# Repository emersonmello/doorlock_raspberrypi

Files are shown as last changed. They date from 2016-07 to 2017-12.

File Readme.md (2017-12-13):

# Door lock NFC card reader for Raspberry PI

## Motivation

Is it possible to use [FIDO UAF Standard](https://fidoalliance.org/specifications/download/) on an Android mobile + NFC to opening doors?

This project is a simple prototype to verify how FIDO could be used in this scenario (see [FIDO Security Reference](https://fidoalliance.org/specs/fido-uaf-v1.0-ps-20141208/fido-security-ref-v1.0-ps-20141208.html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)). This [card reader](https://github.com/emersonmello/doorlock_raspberrypi) uses NFC to communicate with a specific [Android Opening Door App](https://github.com/emersonmello/openingdoor), that emulates a NFC card using Android's [Host-based Card Emulation](https://developer.android.com/guide/topics/connectivity/nfc/hce.html) functionality.

The [card reader](https://github.com/emersonmello/doorlock_raspberrypi) and [Android Opening Door App](https://github.com/emersonmello/openingdoor) depend of a third-party, called [FIDO UAF RP Server](https://github.com/emersonmello/UAF).

Figure below shows all necessary components and the relation between them

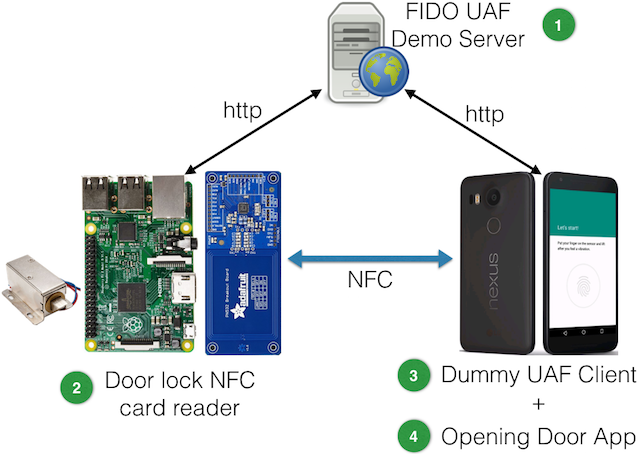
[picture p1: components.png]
Communication diagram


1. [FIDO UAF Demo Server](https://github.com/emersonmello/UAF)
  - If you prefer, there is a [Docker container](https://www.docker.com/what-docker) ready to use here: https://github.com/emersonmello/docker-fidouafserver
2. [Door lock NFC card reader](https://github.com/emersonmello/doorlock_raspberrypi) <- You are working on it right now!
3. [Dummy FIDO UAF Client](https://github.com/emersonmello/dummyuafclient)
4. [Opening Door Android App](https://github.com/emersonmello/openingdoor)

## Hardware requirements

- 01 [Raspberry PI 2 B](https://www.raspberrypi.org/products/raspberry-pi-2-model-b/) or 01 [Raspberry PI 3 B](https://www.raspberrypi.org/products/raspberry-pi-3-model-b/)
- 01 [Adafruit PN532](https://www.adafruit.com/products/364) or 01 [Elechouse PN532 NFC RFID module V3](http://www.elechouse.com/elechouse/index.php?main_page=product_info&cPath=90_93&products_id=2242)
- 01 Breadboard to connect raspberry and PN532
- 01 [N channel MOSFET](https://www.adafruit.com/products/355)
- 01 [Lock-style solenoid](https://www.adafruit.com/product/1512)
- 02 Resistors - 300 Ohms
- 02 LED (red and green)
- 02 [Diode 1N4001](https://www.adafruit.com/product/755)

### Wiring Raspberry PI 2 B (or Raspberry PI 3 B) & PN532

1. To use UART on [Adafruit PN532](https://www.adafruit.com/products/364) breakout you must set to **OFF** the **SEL0** and **SEL1** jumpers
   1. To use UART on [Elechouse PN532 NFC RFID module V3](http://www.elechouse.com/elechouse/index.php?main_page=product_info&cPath=90_93&products_id=2242) you must set to **OFF** the **switch 1** and **switch 2**.
2. Follow instructions (and pictures) below to connect all components

| Raspberry PI (2 or 3) B | Wire color | Adafruit PN532 | Elechouse PN532 |
| --- | :---: | :---: | :---: |
| Pin 2 (5v) | RED | 5.0V | VCC |
| Pin 6 (ground) | BLACK | GND | GND |
| Pin 8 (BCM 14 TXD) | YELLOW | RXD | SCL (RX) |
| Pin 10 (BCM 15 RXD) | GREEN | TXD | SDA (TX) |

| Raspberry PI 2 or 3 B | Wire color | Component on breadboard  |
| --- | :---: | :---: |
| Pin 11 (BCM 17) | ORANGE | Green LED anode (+) |
| Pin 13 (BCM 27) | BLUE | RED LED anode (+) |
| Pin 15 (BCM 22) | PURPLE | Diode #1 anode (+) |
| Pin 39 (Ground) | BLACK | Breadboard negative rail |

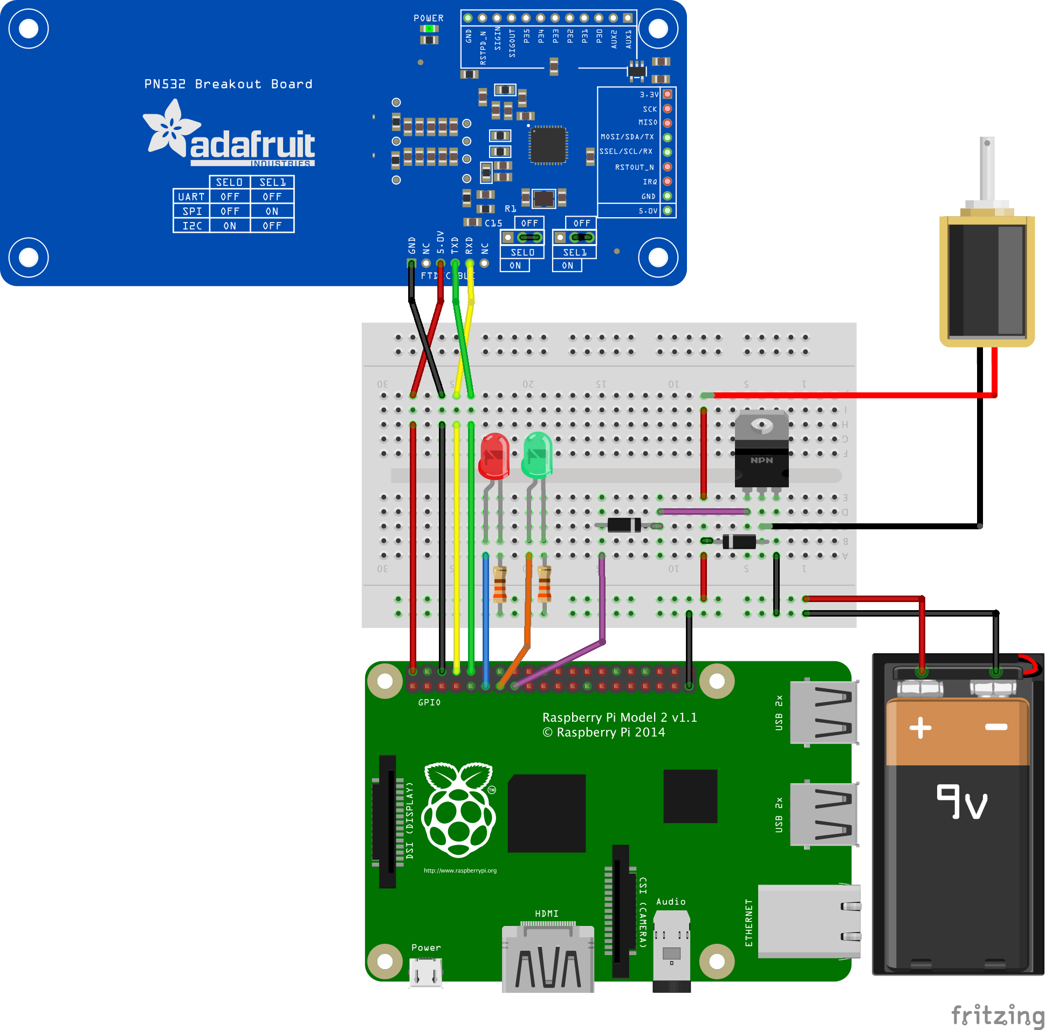
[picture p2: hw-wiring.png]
Using Adafruit PN532 Wiring raspberry PI 2/3 B & Adafruit PNB532 & solenoid


Or, if you have an Elechouse PN532:

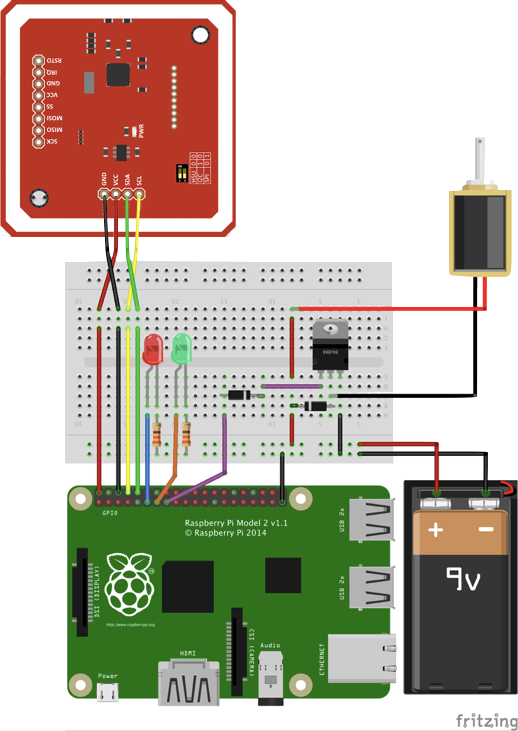
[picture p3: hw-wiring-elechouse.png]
Using Elechousr PN532 Wiring raspberry PI 2/3 B & Elechouse PNB532 & solenoid


## Software requirements

- [Libcurl](https://curl.haxx.se/libcurl/)
- [Libnfc >= 1.7.1](https://github.com/nfc-tools/libnfc)
- [Json-c >= 0.11-4](https://github.com/json-c/json-c)
- [wiringPi library](http://wiringpi.com/)

### Installing required packages

	sudo apt-get install git build-essential autoconf libtool libpcsclite-dev
	sudo apt-get install libusb-dev libcurl4-openssl-dev libjson-c-dev

### Freeing [UART](https://www.raspberrypi.org/documentation/configuration/uart.md)

  sudo raspi-config

#### On the Raspberry PI 2 B running Raspbian GNU/Linux 8

- Select option  "Advanced Options"
- Select option "Serial" and select **NO**
- Finish and reboot: `sudo shutdown -r now`

#### On the Raspberry PI 3 B running Raspbian Stretch

- Select option "Interface options"
- Select option "Serial", and select **NO**
  - Choose **YES** for *Would you like the serial port hardware to be enable?*  
- Exit and reboot

### Installing libnfc from source

```cd ~ && sudo mkdir -p /etc/nfc/devices.d
git clone https://github.com/nfc-tools/libnfc.git
cd libnfc
sudo mkdir -p /etc/nfc/devices.d/
```

#### On the Raspberry PI 2 B

`sudo cp contrib/libnfc/pn532_uart_on_rpi.conf.sample /etc/nfc/devices.d/pn532_uart_on_rpi.conf`

`echo "allow_instrusive_scan =  true" | sudo tee -a  /etc/nfc/devices.d/pn532_uart_on_rpi.conf`

#### On the Raspberry PI 3 B

`sudo cp contrib/libnfc/pn532_uart_on_rpi_3.conf.sample /etc/nfc/devices.d/pn532_uart_on_rpi_3.conf`

#### Run config & build

	autoreconf -vis
	./configure --with-drivers=pn532_uart --sysconfdir=/etc --prefix=/usr
	sudo make clean && sudo make install all

#### Testing

You can test your setup reading an ISO14443-A card using `nfc-poll` program that came with `libnfc`. Place a card on the reader and run the command:

	cd ~/libnfc/examples
	sudo ./nfc-poll

### Installing wiringPi from source

- Please, follow the instructions provided by [official website](http://wiringpi.com/download-and-install). Or

- ```
  git clone git://git.drogon.net/wiringPi
  cd ~/wiringPi
  sudo ./build
  ```

## Running door lock NFC card reader on Raspberry PI

1. Get the source code
- `cd ~ && git clone https://github.com/emersonmello/doorlock_raspberrypi.git`
- `cd doorlock_raspberrypi`
2. Change **HOSTNAME** and **PORT** values on [Door lock NFC card reader's rp_settings.h file](https://github.com/emersonmello/doorlock_raspberrypi/blob/master/rp_settings.h) to the **IP Address** and **PORT** where you are running the **FIDO UAF Demo Server**
  - For instance: `nano rp_settings.h`
3. Compile **Door lock NFC card reader** project
  - `make clean && make`
4. Run it (sorry, you must be root because it is a requirement of wiringPi lib)
    - For instance: `sudo ./dist/Debug/GNU-MacOSX/doorlock_raspberrypi`

### Setting up FIDO UAF Demo Server and Android Apps

#### FIDO UAF Demo Server

1. Start **FIDO UAF Demo Server**
- Follow the instructions provided by:
  - [FIDO UAF Demo Server](https://github.com/emersonmello/UAF)
  - Or, if you prefer, there is a [Docker container](https://www.docker.com/what-docker) ready to use [here](https://github.com/emersonmello/docker-fidouafserver)

#### On Android Phone

1. Install [Dummy FIDO UAF Client](https://github.com/emersonmello/dummyuafclient) on your Android phone
2. Install [Opening Door Android App](https://github.com/emersonmello/openingdoor) on your Android phone
3. On **Opening Door Android App** touch on "Settings" on the main application menu and update "server endpoint" field to the **IP Address** and **PORT** where you are running the **FIDO UAF Demo Server**  
4. On **Opening Door Android App** touch on "Whitelisting facetID" (to follow [FIDO UAF specifications](https://fidoalliance.org/specs/fido-uaf-v1.1-id-20170202/fido-appid-and-facets-v1.1-id-20170202.html) ).
   1. Or you can do it: On **Opening Door Android App** touch on "See app facetID" on the main application menu and insert the showed value in [FIDO UAF Demo Server](https://github.com/emersonmello/UAF) MySQL database. For instance: ```INSERT INTO facets (fDesc) values ('android:apk-key-hash:Lir5oIjf552K/XN4bTul0VS3GfM')```

### Testing the whole thing

1. Open **Opening Door Android App** and touch "Register" button
2. Tap your mobile phone on "NFC reader"
3. Follow the instructions provided by application (i.e. put your finger on the sensor, etc.) and you should see the message "Access Granted"

## UML Sequence Diagram

![alt text](sd_doorlock.png "Communication diagram")

## Starting door lock automatically on Raspberry boot

I'm using [supervisord](http://supervisord.org/) to handle this task because it can also restart a failed process

1. Copy `doorlock_raspberrypi` binary to /usr/local/bin
  - `sudo cp ~/doorlock_raspberrypi/dist/Debug/GNU-Linux/doorlock_raspberrypi /usr/local/bin`
2. Installing python2.7
    - `sudo apt-get install python`
3. Installing supervisord
    - `sudo easy_install supervisor`
    - `echo_supervisord_conf | sudo tee /etc/supervisord.conf`
4. Adding a program section to supervisord's configuration file
    - Add the follow lines at the end of **/etc/supervisord.conf** file
 ```
[program:doorlock]
command=/usr/local/bin/doorlock_raspberrypi
 ```
- For instance:
```
printf "[program:doorlock]\n command=/usr/local/bin/doorlock_raspberrypi \n" | sudo tee -a  /etc/supervisord.conf
```
5. Download [supervisord.sh](supervisord.sh) file and save it at `/etc/init.d`
 ```
sudo cp ~/doorlock_raspberrypi/supervisord.sh /etc/init.d
sudo chmod 755 /etc/init.d/supervisord.sh
sudo update-rc.d supervisord.sh defaults
 ```

## References

- https://learn.adafruit.com/adafruit-nfc-rfid-on-raspberry-pi/
- https://curl.haxx.se/libcurl/c/libcurl-tutorial.html
- https://gist.github.com/leprechau/e6b8fef41a153218e1f4
- https://github.com/nfc-tools/libnfc/tree/master/examples
- https://netbeans.org/kb/docs/cnd/remotedev-tutorial.html
- http://pinout.xyz/

![alt text](pinout.png "Raspberry PI 2 B pinout")

 ```

 ```

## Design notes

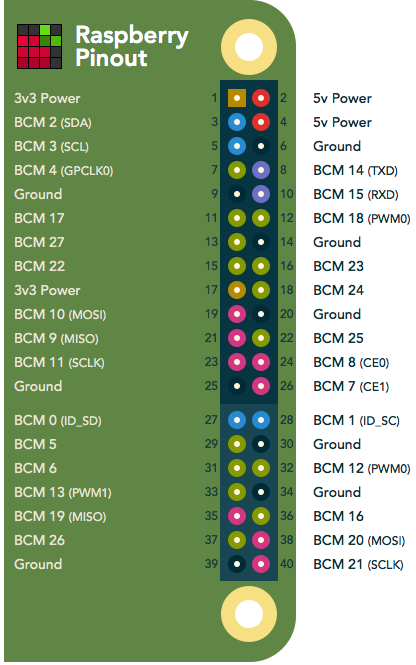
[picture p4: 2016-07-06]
pinout.png

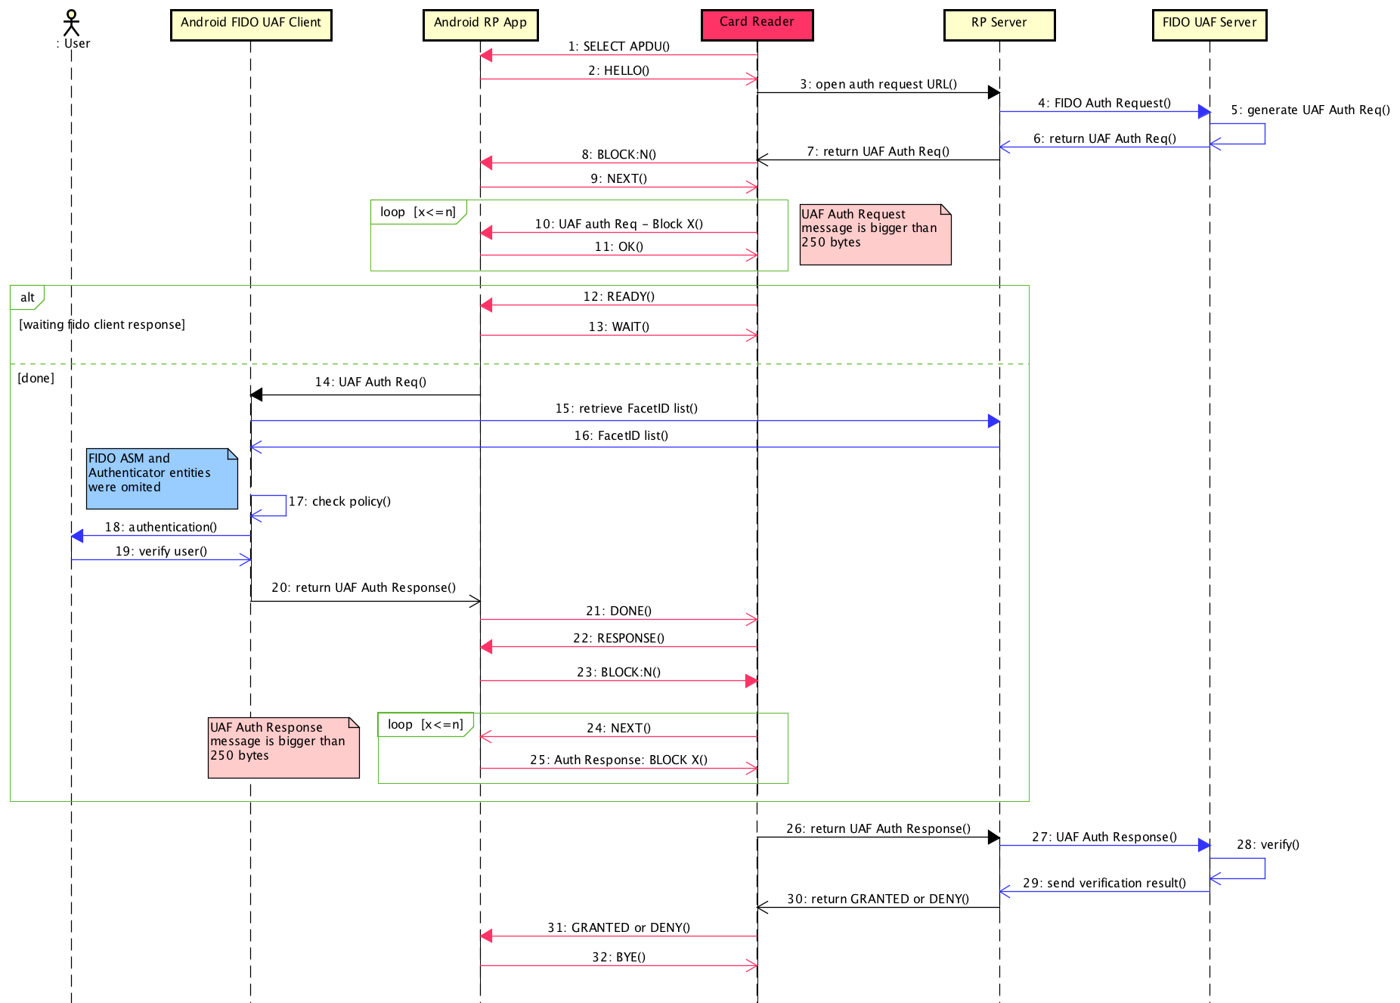
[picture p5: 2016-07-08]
sd_doorlock.png

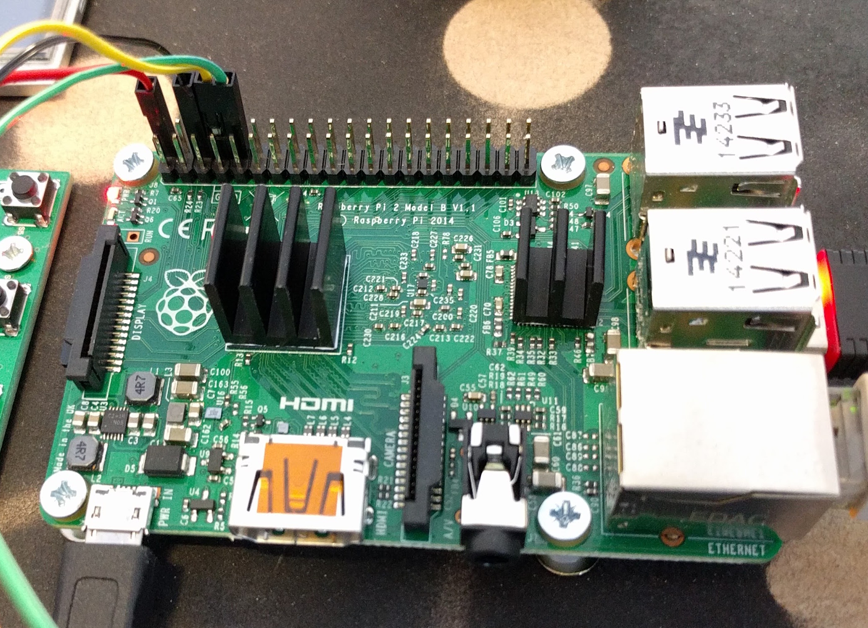
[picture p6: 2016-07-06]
extras/raspberry.jpg

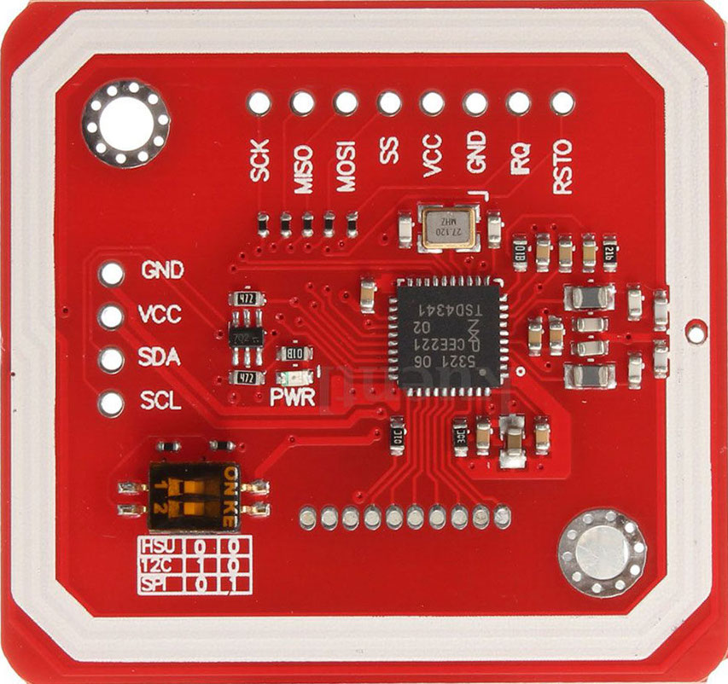
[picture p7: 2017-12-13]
extras/elechouse-pn532-photo.jpg

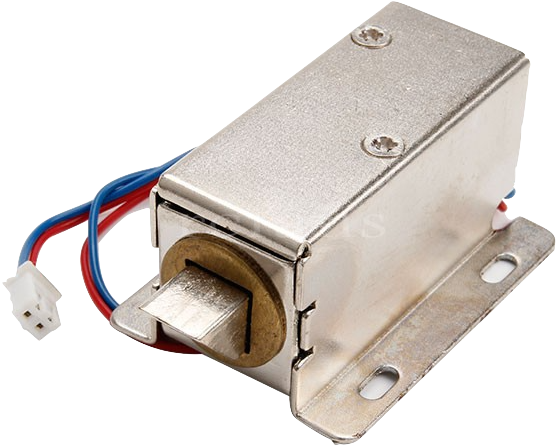
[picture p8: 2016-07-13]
extras/doorlock-solenoide.png

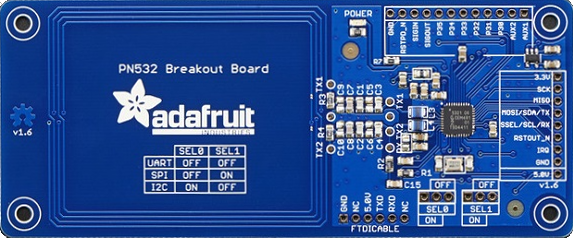
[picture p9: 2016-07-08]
extras/pn532.png

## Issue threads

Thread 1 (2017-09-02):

libjson0-dev dependency install-issues

sleepdefic1t, 2017-09-02:
Raspberry Pi Zero W
Jessie Stretch lite

```sudo apt-get install libjson0-dev```
```
Reading package lists... Done
Building dependency tree
Reading state information... Done
E: Unable to locate package libjson0-dev
```

So I ```sudo nano /etc/apt/sources.list```,
then add the line ```deb http://ftp.de.debian.org/debian jessie main```;
per instructions @ [**libjson0-dev packages.debian.org**](https://packages.debian.org/jessie/armhf/libjson0-dev/download).

Next,
```sudo apt-get update```.

Then,
```sudo apt-get install libjson0-dev``` returns ```libjson0-dev : Depends: libjson-c-dev (= 0.11-4)```.

so I,
```sudo apt-get install libjson-c-dev=0.11-4```.

Finally, ```sudo apt-get install libjson0-dev``` installs okay.

sleepdefic1t, 2017-09-02:
Checking it out futher...

https://github.com/TurboGit/hubicfuse/issues/139

libjson0-dev is deprecated in Raspbian Stretch.

```sudo apt-get install libjson-c-dev``` will install the correct frameworks. ```libjson-c-dev``` &  ```libjson-c3```

emersonmello, 2017-09-02:
Hi @sleepdefic1t ,

Thank you so much. I made changes on Readme.md.

sleepdefic1t, 2017-09-02:
Not a problem.

I'm working on something similar and yours is by far one of the most well done I've seen!
Keep up the great work!

GowrishankarGeek, 2018-09-04:
Hi @sleepdefic1t,
The same library I am trying to install in alpine docker image. can you please help on that.

Closed 2017-09-02.

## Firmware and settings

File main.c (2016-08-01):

/* 
 * File:   main.c
 * Author: Emerson Ribeiro de Mello <mello@ifsc.edu.br>
 *
 * Created on 30 June 2016, 09:33
 */

#include <stdio.h>
#include <stdlib.h>
#include <string.h>
#include <unistd.h>
#include <signal.h>
#include <limits.h>
#include <nfc/nfc.h>   
#include "rp_settings.h"
#include "curlutils.h"
#include "wiring-gpio.h"


nfc_device *pnd;
nfc_target nt;
nfc_context *context;

void signal_handler(int signal) {

    switch (signal) {
        case SIGHUP:
        case SIGUSR1:
        case SIGINT:
        case SIGTERM:
        case SIGQUIT:
            printf("\nFinalizing....\n");
            cleaning();
            exit(EXIT_SUCCESS);
        default:
            fprintf(stderr, "\nCaught wrong signal: %d\n", signal);
            exit(EXIT_FAILURE);
    }
}

char *charToHex(char *str) {
    int size = strlen(str);
    int i;
    char *buf_str = (char *) malloc(4 * size + 1);
    char *buf_ptr = buf_str;

    for (i = 0; i < size; i++) {
        buf_ptr += sprintf(buf_ptr, "\\x%02X", str[i]);
    }
    sprintf(buf_ptr, "\n");
    *(buf_ptr + 1) = '\0';
    return buf_ptr;
}

int CardTransmit(nfc_device *pnd, uint8_t *capdu, size_t capdulen, uint8_t *rapdu, size_t *rapdulen) {
    int res;
    size_t szPos;
    //    printf("=> ");
    //    for (szPos = 0; szPos < capdulen; szPos++) {
    //        printf("%hhx ", capdu[szPos]);
    //    }
    //    printf("\n");
    if ((res = nfc_initiator_transceive_bytes(pnd, capdu, capdulen, rapdu, *rapdulen, 500)) < 0) {
        return -1;
    } else {
        *rapdulen = (size_t) res;
        //        printf("<= ");
        //        for (szPos = 0; szPos < *rapdulen; szPos++) {
        //            printf("%hhx ", rapdu[szPos]);
        //        }
        //        printf("\n");
        //        for (szPos = 0; szPos < *rapdulen; szPos++) {
        //            printf("%c", (char) rapdu[szPos]);
        //        }
        //        printf("len: %d\n", *rapdulen);
        return 0;
    }
}

void nfcInitListen() {
    const char *acLibnfcVersion = nfc_version();
    pnd = nfc_open(context, NULL);
    if (pnd == NULL) {
        printf("ERROR: %s", "Unable to open NFC device.");
        exit(EXIT_FAILURE);
    }
    if (nfc_initiator_init(pnd) < 0) {
        nfc_perror(pnd, "nfc_initiator_init");
        exit(EXIT_FAILURE);
    }
    printf("NFC reader: %s opened\n", nfc_device_get_name(pnd));
}

void nfcProtocol() {
    char message[1024];
    char UAFMessage[2048];
    memoryStruct chunk;

    uint8_t capdu[264];
    size_t capdulen;
    uint8_t rapdu[264];
    size_t rapdulen;
    char *response = 0;


    const nfc_modulation nmMifare = {
        .nmt = NMT_ISO14443A,
        .nbr = NBR_106,
    };

    printf("Polling for target...\n");
    while (nfc_initiator_select_passive_target(pnd, nmMifare, NULL, 0, &nt) <= 0);
    printf("Target detected!\n");


    // Select application
    memcpy(capdu, APDU, sizeof (APDU));
    capdulen = sizeof (APDU); // 13
    rapdulen = sizeof (rapdu);
    if (CardTransmit(pnd, capdu, capdulen, rapdu, &rapdulen) < 0)
        exit(EXIT_FAILURE);
    printf("Application selected!\n");

    if (strncmp(rapdu, DOOR_HELLO, (int) rapdulen)) {
        printf("** Opss ** I'm expecting HELLO msg, but card sent to me: %s. len: %d\n", response, (int) rapdulen);
        return;
    }

    // FIDO Auth Request Message
    printf("Doing AuthRequest to FIDO UAF Server\n");
    sprintf(UAFMessage, AUTH_REQUEST_MSG, SCHEME, HOSTNAME, PORT, AUTH_REQUEST_ENDPOINT);
    chunk = getHttpRequest(UAFMessage);

    if (chunk.size <= 0) {
        printf("** Opss ** Error to connect to FIDO Server\n");
        memcpy(capdu, "ERROR", 5);
        capdulen = 5;
        rapdulen = sizeof (rapdu);
        if (CardTransmit(pnd, capdu, capdulen, rapdu, &rapdulen) < 0) {
            printf("Error to sent error message to card...\n");
        }
        return;
    }

    size_t blocks = (chunk.size / BLOCK_SIZE) + 1;

    char *buffer[blocks];
    blockSplit(chunk.memory, buffer, blocks);
    sprintf(message, "BLOCK:%ld", blocks);
    printf("Sending number of blocks: %s\n", message);
    free(chunk.memory);

    memcpy(capdu, message, strlen(message));
    capdulen = strlen(message);
    rapdulen = sizeof (rapdu);
    if (CardTransmit(pnd, capdu, capdulen, rapdu, &rapdulen) < 0) {
        printf("Error to send number of blocks\n");
        return;
    }

    int totalSent = 0;

    if (strncmp(rapdu, DOOR_NEXT, (int) rapdulen)) {
        printf("** Opss ** I'm expecting NEXT msg, but card sent to me: %s. len: %d", response, (int) rapdulen);
        return;
    }

    response = NULL;
    do { // Sending UAFRequestMessage to card
        memcpy(capdu, buffer[totalSent], strlen(buffer[totalSent]));
        capdulen = strlen(buffer[totalSent]);
        rapdulen = sizeof (rapdu);
        if (CardTransmit(pnd, capdu, capdulen, rapdu, &rapdulen) < 0) {
            int i = strlen(buffer[totalSent]);
            printf("error to send UAFRequestMessage to card. Message size: %d, message: %s\n", i, buffer[totalSent]);
            return;
        }

        if (strncmp(rapdu, DOOR_OK, (int) rapdulen)) {
            printf("** Opss ** I'm expecting OK msg, but card sent to me: %s. len: %d", response, (int) rapdulen);
            return;
        }
        response = NULL;
        free(buffer[totalSent]);
        totalSent++;
    } while (totalSent < blocks);


    printf("Sending READY!\n");
    memcpy(capdu, DOOR_READY, sizeof (DOOR_READY));
    capdulen = strlen(DOOR_READY);
    rapdulen = sizeof (rapdu);
    unsigned long timeout = LONG_MAX;
    do {
        if (CardTransmit(pnd, capdu, capdulen, rapdu, &rapdulen) < 0) {
            printf("Error to received WAIT\n");
            return;
        }

        if (strncmp(rapdu, DOOR_WAIT, (int) rapdulen) == 0) {
            continue;
        }

        if (strncmp(rapdu, DOOR_DONE, (int) rapdulen) == 0) {
            printf("Sending RESPONSE!\n");
            memcpy(capdu, DOOR_RESPONSE, sizeof (DOOR_RESPONSE));
            capdulen = strlen(DOOR_RESPONSE);
            rapdulen = sizeof (rapdu);
            if (CardTransmit(pnd, capdu, capdulen, rapdu, &rapdulen) < 0) {
                printf("Error RESPONSE...\n");
                return;
            }
            break;
        }
        timeout--;
    } while (timeout > 0);

    if (timeout == 0) {
        printf("Error. Client is not responding...\n");
        return;
    }

    strncpy(message, rapdu, (int) rapdulen);
    char *p = strtok(message, ":");
    char *endptr;
    long val;
    if (strcmp(p, "BLOCK") == 0) {
        p = strtok(NULL, ":");
        val = strtol(p, &endptr, 10);
        char *UAFmsg = malloc(sizeof (char) * BLOCK_SIZE * val + 1);
        UAFmsg[0] = '\0';
        do {
            printf("Sending NEXT!\n");
            memcpy(capdu, DOOR_NEXT, sizeof (DOOR_NEXT));
            capdulen = strlen(DOOR_NEXT);
            rapdulen = sizeof (rapdu);
            if (CardTransmit(pnd, capdu, capdulen, rapdu, &rapdulen) < 0) {
                printf("Error NEXT\n");
                return;
            }
            strncat(UAFmsg, rapdu, (int) rapdulen);
            val--;
        } while (val > 0);
        // FIDO Auth Request Message
        printf("Forwarding card response to FIDO UAF Server: \n");
        sprintf(UAFMessage, AUTH_REQUEST_MSG, SCHEME, HOSTNAME, PORT, AUTH_RESPONSE_ENDPOINT);
        //curlFetchStruct *result = postHttpRequest(UAFMessage, UAFmsg);
        json_object *result = postHttpRequest(UAFMessage, UAFmsg);
        free(UAFmsg);

        //        if (result->size <= 0) {
        if (result == NULL) {
            printf("Error to connect to FIDO Server\n");
            memcpy(capdu, "ERROR", 5);
            capdulen = 5;
            rapdulen = sizeof (rapdu);
            if (CardTransmit(pnd, capdu, capdulen, rapdu, &rapdulen) < 0) {
                printf("Error to send response to card\n");
            }
            return;
        }
        printf("Resul payload: %s \n", json_object_to_json_string(result));
        const char *resultStr = json_object_to_json_string(result);

        
        if (strstr(resultStr, "SUCCESS") == NULL) {
            printf("Access denied!\n");
            memcpy(capdu, DOOR_DENY, sizeof (DOOR_DENY));
            capdulen = strlen(DOOR_DENY);
            rapdulen = sizeof (rapdu);
            if (CardTransmit(pnd, capdu, capdulen, rapdu, &rapdulen) < 0) {
                return;
            }
        } else {
            printf("Access granted!\n");
            memcpy(capdu, DOOR_GRANTED, sizeof (DOOR_GRANTED));
            capdulen = strlen(DOOR_GRANTED);
            rapdulen = sizeof (rapdu);
            if (CardTransmit(pnd, capdu, capdulen, rapdu, &rapdulen) < 0) {
                return;
            }
            doorlock(1);
            doorlock(0);
        }
        /* free json object */
        json_object_put(result);
        
        strncpy(message, rapdu, (int) rapdulen);
        if (strstr(message, "BYE") != NULL) {
            printf("bye!\n");
        } else {
            printf(":-(\n");
        }
    }
}

/*
 * 
 */
int main(int argc, char** argv) {

    // Handling Linux Signals
    if (signal(SIGHUP, signal_handler) == SIG_ERR) {
        perror("\nCan't catch SIGHUP\n");
    }
    if (signal(SIGQUIT, signal_handler) == SIG_ERR) {
        perror("\nCan't catch SIGQUIT\n");
    }
    if (signal(SIGUSR1, signal_handler) == SIG_ERR) {
        perror("\nCan't catch SIGUSR1\n");
    }
    // supervisord will send this one
    if (signal(SIGTERM, signal_handler) == SIG_ERR) {
        perror("\nCan't catch SIGTERM\n");
    }
    if (signal(SIGINT, signal_handler) == SIG_ERR) {
        perror("\nCan't catch SIGINT\n");
    }

    // About GPIO & wiringPI Lib
    setupWiring();

    while (1) {
        nfc_init(&context);
        if (context == NULL) {
            printf("Unable to init libnfc (malloc)\n");
            exit(EXIT_FAILURE);
        }
        nfcInitListen();
        nfcProtocol();
        nfc_close(pnd);
        nfc_exit(context);
        sleep(2);
        printf("starting again...\n");
    }

    return (EXIT_SUCCESS);
}

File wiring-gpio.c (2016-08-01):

#include "wiring-gpio.h"

void cleaning(){
  digitalWrite (0, LOW);
  digitalWrite (2, LOW);
  digitalWrite (3, LOW);
}

void doorlock(int open){
  
  if (open){
    digitalWrite (0, LOW); 
    digitalWrite (2, HIGH);
    digitalWrite (3, HIGH) ;
    delay (5000);
  }else{ //close
    digitalWrite (0, HIGH); 
    digitalWrite (2, LOW);
    digitalWrite (3, LOW) ;
  }
}

void setupWiring(){
    wiringPiSetup () ;
    
    // wiringPi pin 0 = Physical pin 11 (or BCM pin 17) on Raspberry Pi 2 B
    pinMode (0, OUTPUT) ; 
    // wiringPi pin 2 = Physical pin 13 (or BCM pin 27) on Raspberry Pi 2 B
    pinMode (2, OUTPUT) ;
    // wiringPi pin 3 = Physical pin 15 (or BCM pin 22) on Raspberry Pi 2 B
    pinMode (3, OUTPUT) ;
    
    // red LED is always on when door is locked
    digitalWrite (0, HIGH) ;
    // green LED is always off when door is locked
    digitalWrite (2, LOW) ;
    // Door is locked
    digitalWrite (3, LOW) ;
}

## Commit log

2016-07-08 Initial steps to use GPIO
    [doorlock.fzz, rasp-ada.fzz]
2016-07-21 Adding a physical door lock component
    [rasp-ada.fzz]
2016-08-01 Update figure
    [doorlock.fzz, rasp-ada.fzz]
2016-08-01 Resetting pins states to LOW
    [main.c, wiring-gpio.c]
2017-09-17 New instructions for Raspberry 3 B
2017-12-13 Update Readme.md & Add a section about Raspberry PI 3 B and Elechouse PN532
    [rasp-ada.fzz, rasp-adafruit.fzz, rasp-elechouse.fzz]
